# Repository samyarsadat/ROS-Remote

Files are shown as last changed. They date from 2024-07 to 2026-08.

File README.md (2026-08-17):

<h1 align="center">The ROS Remote Project</h1>

<p align="center">
	<br>
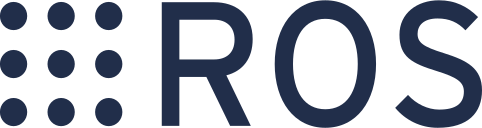
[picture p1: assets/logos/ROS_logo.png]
	<br>
	<br><br>
	
	|
	
	<br><br>
</p>

----
> [!NOTE]
> All features of the remote are currently functional; however, further development is expected.

<br>

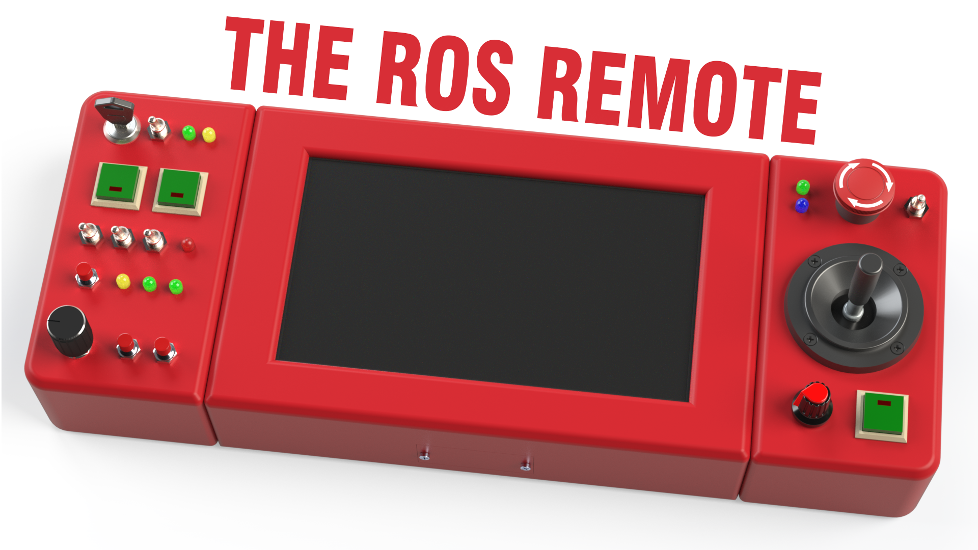
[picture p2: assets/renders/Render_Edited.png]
3D render of ROS Remote CAD drawings

This is a 3D render of the CAD drawings.

<br>

## Overview
The ROS Remote is a comprehensive remote controller for ROS-based robots. The hardware can, of course, be used with any robot, given that specific software has been prepared for the remote.

<br>

### Hardware
The remote houses a 7-inch Waveshare touchscreen, a Raspberry Pi 4B 8GB (you can use a 4GB Pi, or a Pi 5 as well, bu I wouldn't recommend anything below the Pi 4), a Raspberry Pi Pico (Pico 1, though a Pico 2 can also be used with some changes to the build configuration of the firmware), and a USB power bank with enough output current capacity to power the Pi and display (3A should be enough. Must be no larger than 62 x 92 x 24mm, please see CAD drawings).

The buttons, switches, and LEDs are all connected to the Raspberry Pi Pico (except for the rotary encoder and three toggle switches on the left side, which are directly connected to the Pi 4's GPIO pins). The Pico exposes two HID device interfaces. One is a generic joystick interface (for buttons, switches, 2-axis joystick, and potentiometer), and the other is a "custom" (vendor-defined HID reports) interface for controlling the LEDs.

<br>

### Software
The `joy_linux` ROS driver package can be used for publishing data from the joystick interface as a `sensor_msgs/msg/Joy` message to a given topic, and the `joy_teleop` package can be used for robot teleopertation using the `Joy` message. A custom driver package can be found in this repository for interfacing with the LEDs using ROS.

A custom GUI has also been prepared for the screen, which can display a camera feed as well as data from a number of other sensors. This GUI program is designed specifically for use with my [ROS Robot Project](https://github.com/samyarsadat/ROS-Robot), and it is also slightly lacking in terms of performance.

I plan on overhauling this program to improve performance, and make it robot-agnostic. As it stands, any robot which accepts `geometry_msgs/msg/Twist` messages can be teleoperated using the remote with minimal configuration. Additionally, RViz can be used for visualizations, camera feed display, etc. until the remote's own custom GUI program is made robot-agnostic.

You can, of course, write your own programs to change the states of the remote's LEDs, or perform arbitrary actions upon button presses, etc. as they are/can be exposed as standard ROS nodes. The hardware is quite flexible.

<br>

## File Structure
There are 5 folders in this repository.\
Their names and purposes are as follows:

**.github**\
GitHub issue templates, pull request templates, etc.

**assets**\
Assets used on GitHub (such as images used in this README file).

**cad_files**\
3D CAD design files and 3D printing files.

**electronics**\
Circuit diagrams, and other electrical information.

**source_code**\
Source code for the remote touch UI and Raspberry Pi Pico firmware.<br>

<br>

## Contact
You can contact me via e-mail.\
E-mail: samyarsadat@gigawhat.net\

If you think that you have found a bug or issue please report it [here](../../issues).

<br>

## Contributing
Please take a look at [CONTRIBUTING.md](CONTRIBUTING.md) for contributing.

<br>

---
Copyright © 2024-2025 Samyar Sadat Akhavi.

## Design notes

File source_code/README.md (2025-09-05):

## Software Overview
This project uses ROS 2 Jazzy Jalisco and Ubuntu 24.04 LTS.

<br>

### Raspberry Pi Pico (`pico_ws`)
The source code for the firmware of the Raspberry Pi Pico, all build-related configuration files, and configuration files for a devcpntainer can be found in this directory.

<br>

### Remote GUI (`ros_ws_remote`)
The source code for all ROS 2 packages related to the remote's Graphical User Interface and configuration files for a devcontainer can be found in this directory. The `deployment` subdirectory also contains BASH scripts meant to assist with setup and deployment on a Raspberry Pi Single-Board Computer.

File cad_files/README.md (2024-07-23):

## CAD Files:

### .SLDPRT & .SLDASM:
These files are for people that have access to Solidworks.<br>
These files are ideal for editing.<br>

<br>

### .STEP:
These are editable files that can be opened with almost any CAD software.<br>
These are for people that want to edit the project but don't have Solidworks.<br>

<br>

### .STL:
These are non-editable files used for 3D printing.<br>
They can be easily imported into all 3D printer slicer software.<br>

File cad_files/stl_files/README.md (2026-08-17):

### 3D Printing details:
   - I recommend PLA filament, with 0.25mm layer height, and about 25% infill.

<br>

#### Quantities:
    - 1X Housing_Center_Access_Cover.stl
    - 1X Housing_Center_Backplate.stl
    - 1X Housing_Center_LCD_Brace.stl
    - 1X Housing_Center.stl
    - 1X Housing_Left.stl
    - 1X Housing_Right.stl
    - 2X Housing_Sides_Backplate.stl
    - 1X RPi_Fan_Mount.stl (optional)

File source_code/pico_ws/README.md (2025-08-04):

## Pico Firmware Pre-built Binaries
~~If you don't want to build MicroROS and the Pico firmware from source, pre-built `.uf2` binaries can be found in the `build/src` folder.~~<br>
Please take a look at the [`pico-build` workflow](https://github.com/samyarsadat/ROS-Remote/actions/workflows/pico-build.yml) artifact called 
`pico_binary_artifacts` for the latest binary builds.

#### Action Status
<br>


<br>
<br>

**NOTE: This devcontainer and the following instructions are written with the assumption that the host machine running Docker runs Linux (specifically, Ubuntu)!
If you're using Windows (and can't dualboot Linux), please use the Windows Subsystem for Linux (WSL) to run Docker.**<br>

## Note On Devcontainer
When re-building the devcontainer, the re-build might fail the first time.<br>
In this case, simply retry the build a second time.<br>
<br>
You might have to wait (even after the devcontainer has started) for the MicroROS tools to install.<br>
Reload the devcontainer after you have verified that the MicroROS tools have installed successfully.<br>
(Check whether `~/pico_ws/libmicroros/src/micro_ros_setup/install` exists.)<br>
<br>
When prompted to select a build kit by the CMake Tools extension, select `GCC [version] arm-none-eabi`.

<br>

## Note On Using Debug Probes
If you're using a debug probe (such as the Raspberry Pi Debug Probe), make sure to create
a file named `60-openocd.rules` in `/etc/udev/rules.d` on the host machine (not the devcontainer)
and copy the contents of `https://github.com/raspberrypi/openocd/blob/rp2040-v0.12.0/contrib/60-openocd.rules`
into it. This is so that the probe can be accessed witout having to use `sudo`, which is needed when using
the Cortex-Debug extension in VSCode.<br>
<br>
Run `udevadm control --reload` (again, on the host machine) to make sure that the new rules take effect.

<br>

## Updating the FreeRTOS Kernel
Discard all changes to the submodule repository, pull the latest version, and rebuild the devcontainer.

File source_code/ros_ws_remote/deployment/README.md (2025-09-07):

These scripts are for setting up, running, and updating the ROS Remote GUI. The GUI should be run on a Raspberry Pi (4B 8GB in my case, but a model with less RAM will also work) running Ubuntu 24.04 LTS. Raspberry Pi OS will not work.

You should first run the setup script, then you can add the `run_gui.bash` script to start up the list of startup programs using the GNOME "Startup Applications" app. Be sure to specify the `-r` flag for the `run_gui.bash` script. This makes sure that the screen resolution is set properly. You can enter this into the "Command" field:
```
/bin/bash "/home/[YOUR USERNAME]/ros_remote/source_code/ros_ws_remote/deployment/run_gui.bash" -r
```
Replace `[YOUR USERNAME]` with your username.

<br>

## Note on Wayland
These scripts are written with the assumption that the X Window System is being used. If you are using Wayland, you must either modify these scripts yourself, or you must switch to X11.

On Ubuntu, you can switch to X11 by logging out, clicking on the settings icon, selecting "Ubuntu on Xorg", and then entering your passcode and logging in normally. You only need to do this once, as the change is persistent.

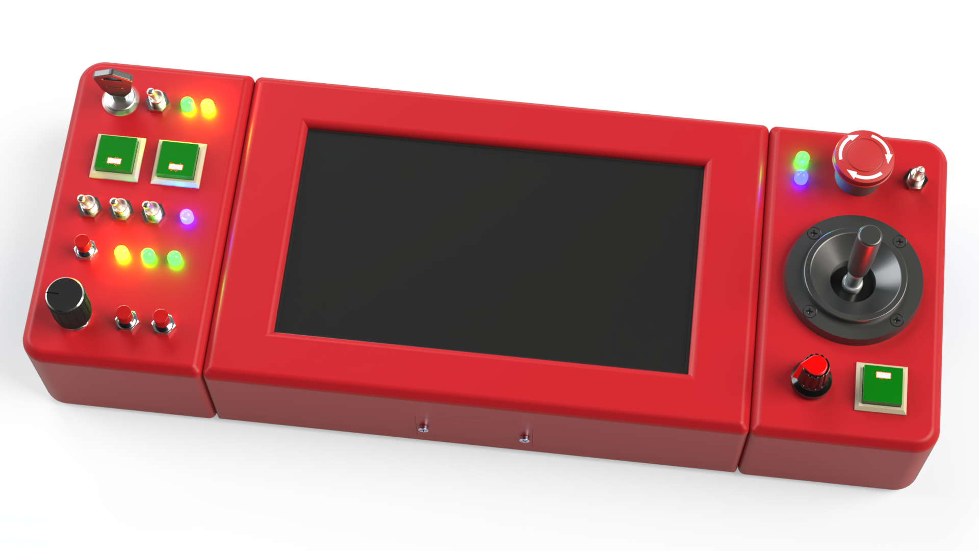
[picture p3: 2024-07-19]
assets/renders/SWVS_Render_Illuminated.png

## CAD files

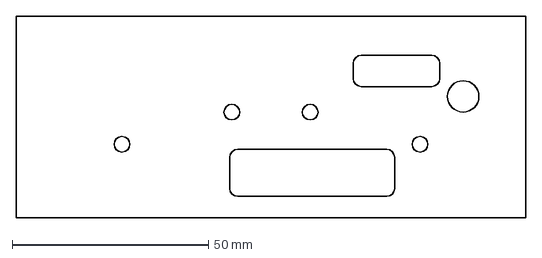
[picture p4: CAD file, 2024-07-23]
cad_files/Housing_Center_Left_Side_Interface.DXF
130.0 x 51.5 mm

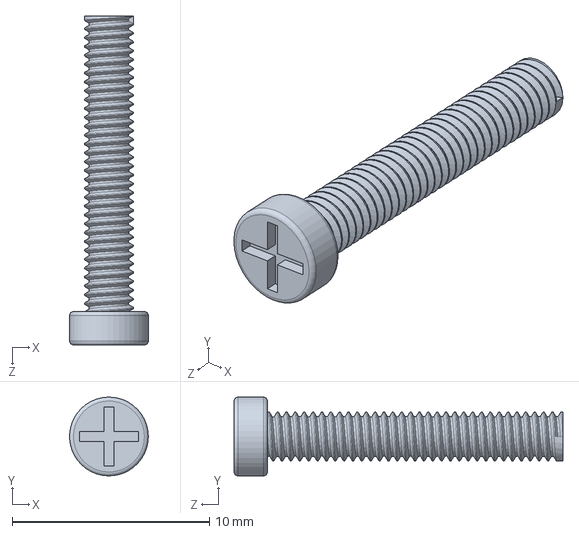
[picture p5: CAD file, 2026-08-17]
cad_files/solidworks_assets/parts/M2.5_15.SLDPRT
3.99 x 4.00 x 16.7 mm

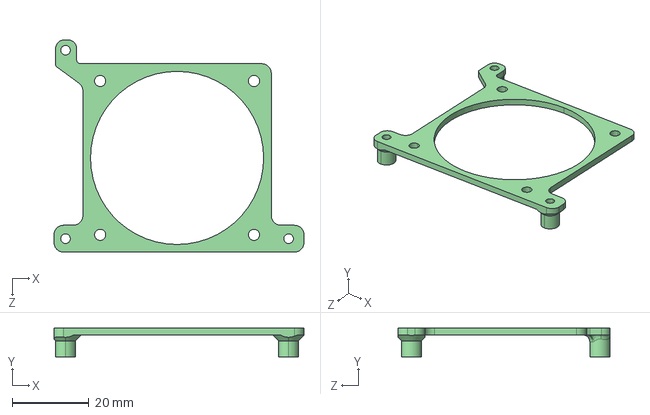
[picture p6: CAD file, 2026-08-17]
cad_files/step_files/RPi_Fan_Mount.STEP
65.0 x 7.50 x 55.2 mm

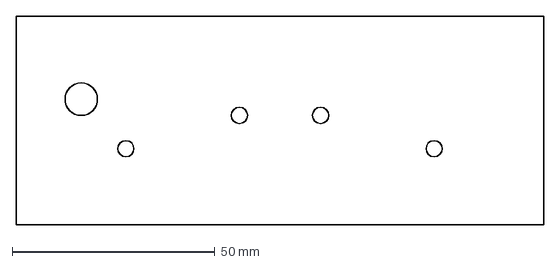
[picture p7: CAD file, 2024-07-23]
cad_files/Housing_Center_Right_Side_Interface.DXF
130.0 x 51.5 mm

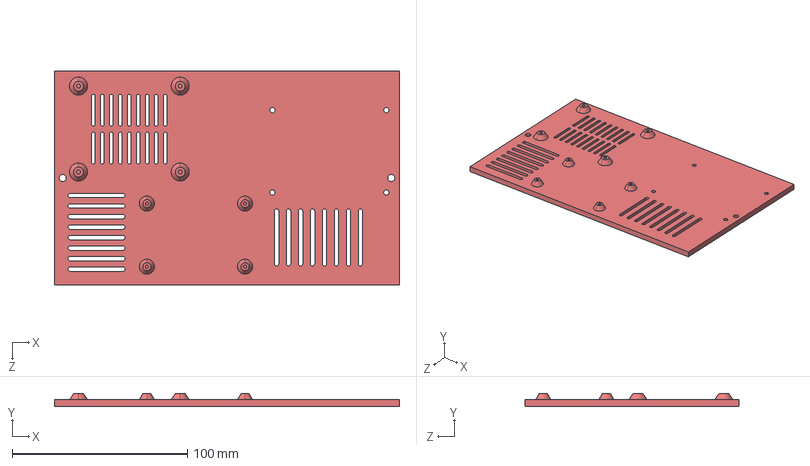
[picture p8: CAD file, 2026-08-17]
cad_files/step_files/Housing_Center_Backplate.STEP
196.8 x 7.50 x 121.8 mm

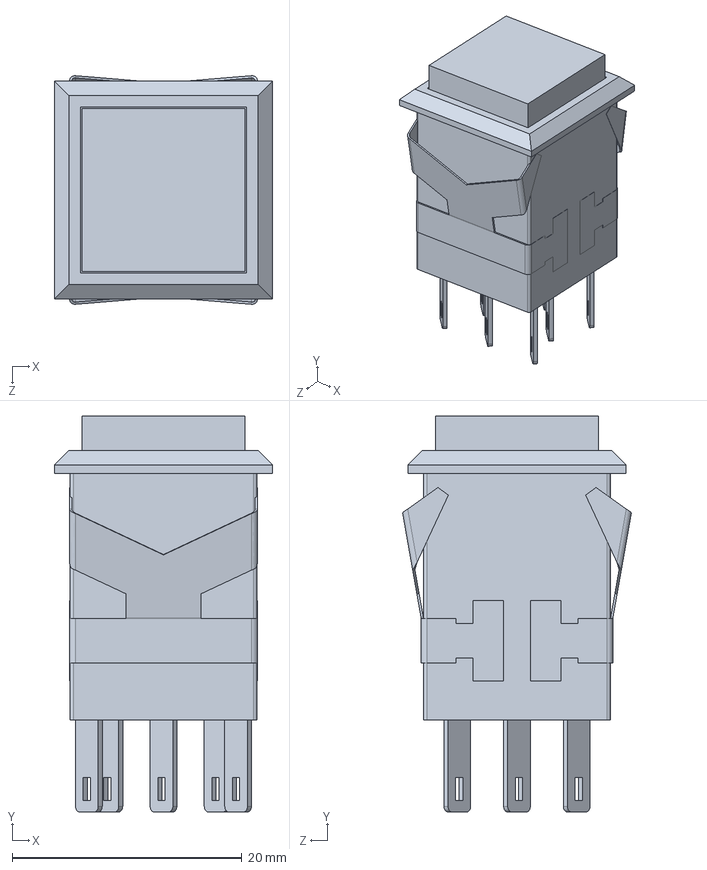
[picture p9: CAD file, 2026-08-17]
cad_files/solidworks_assets/parts/KD2-2X_button_translucent.SLDPRT
19.0 x 34.5 x 19.9 mm

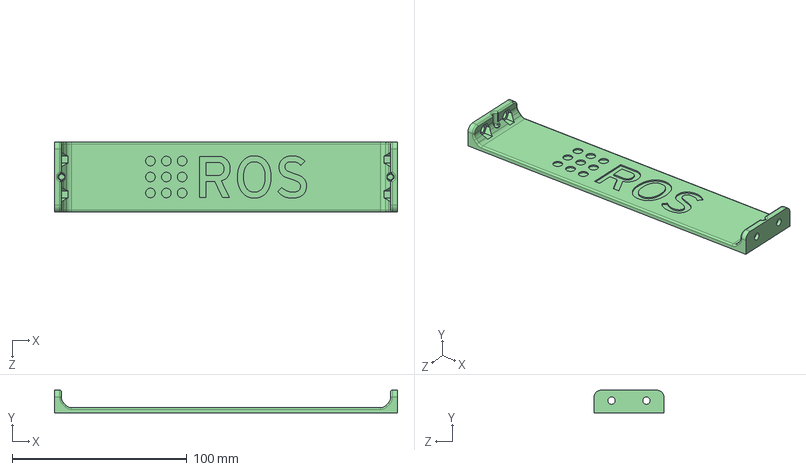
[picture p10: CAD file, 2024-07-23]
cad_files/step_files/Housing_Center_LCD_Brace.STEP
196.5 x 13.0 x 40.0 mm

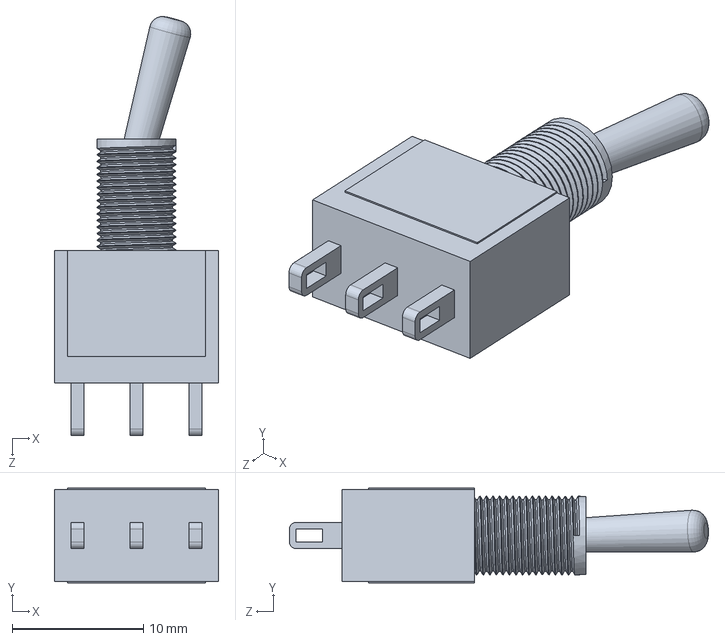
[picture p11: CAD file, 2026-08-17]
cad_files/solidworks_assets/parts/Toggle_Switch.SLDPRT
12.5 x 7.20 x 31.9 mm

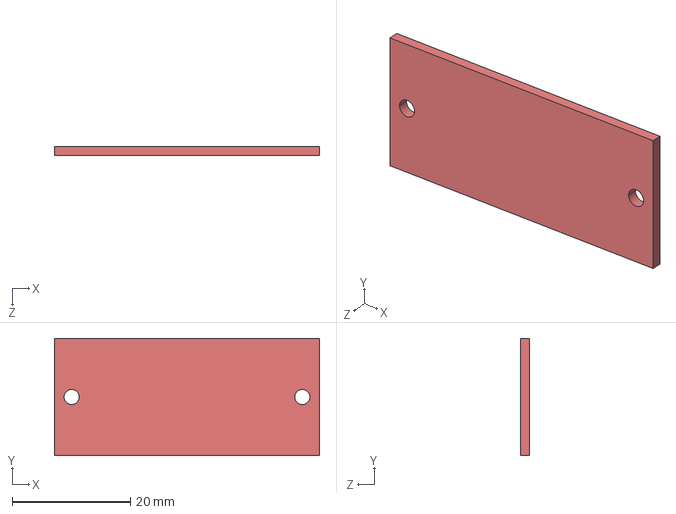
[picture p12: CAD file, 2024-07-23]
cad_files/step_files/Housing_Center_Access_Cover.STEP
44.8 x 19.8 x 1.50 mm

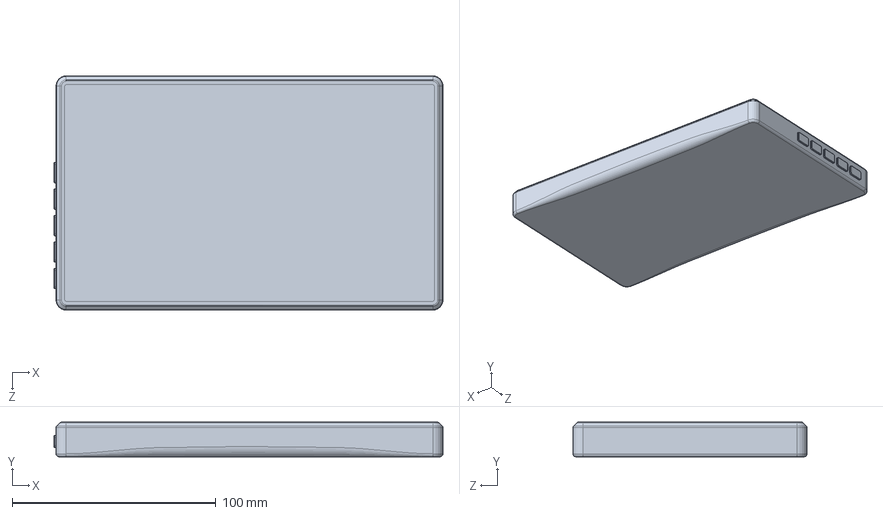
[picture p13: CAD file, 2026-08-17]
cad_files/solidworks_assets/parts/Waveshare_7_inch_HDMI_LCD_H.SLDPRT
191.0 x 17.0 x 115.0 mm

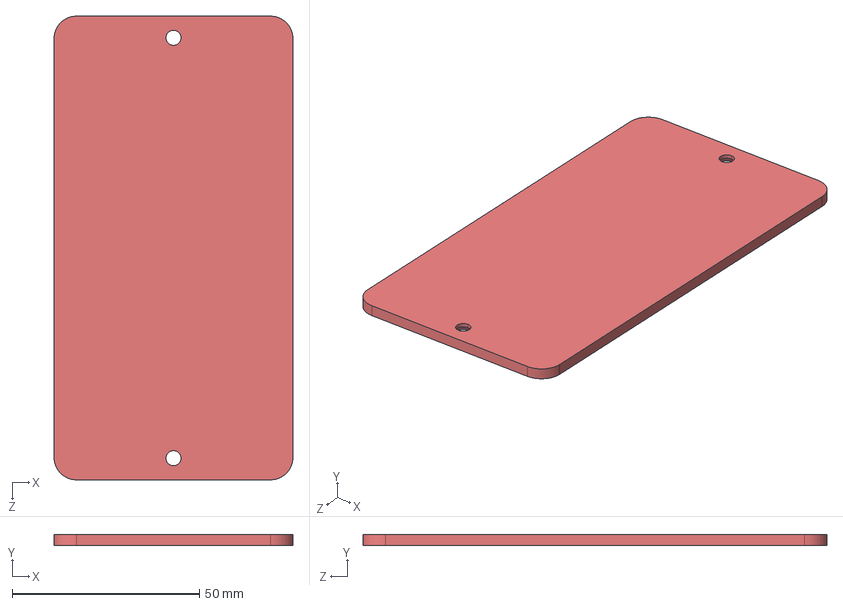
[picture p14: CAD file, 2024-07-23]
cad_files/step_files/Housing_Sides_Backplate.STEP
63.8 x 3.00 x 123.8 mm

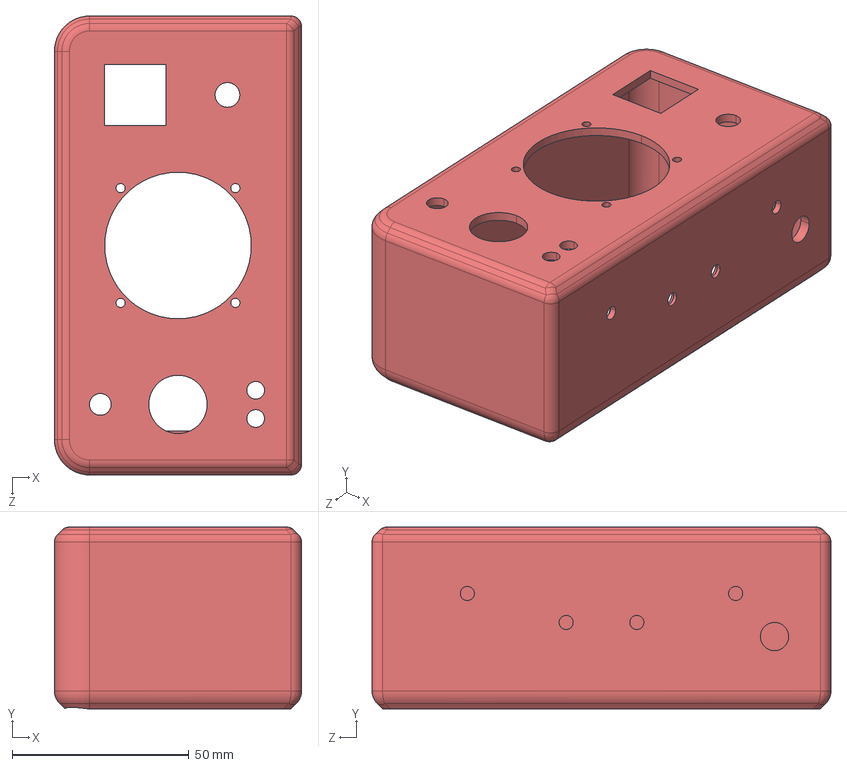
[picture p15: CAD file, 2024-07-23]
cad_files/step_files/Housing_Right.STEP
70.0 x 51.5 x 130.0 mm

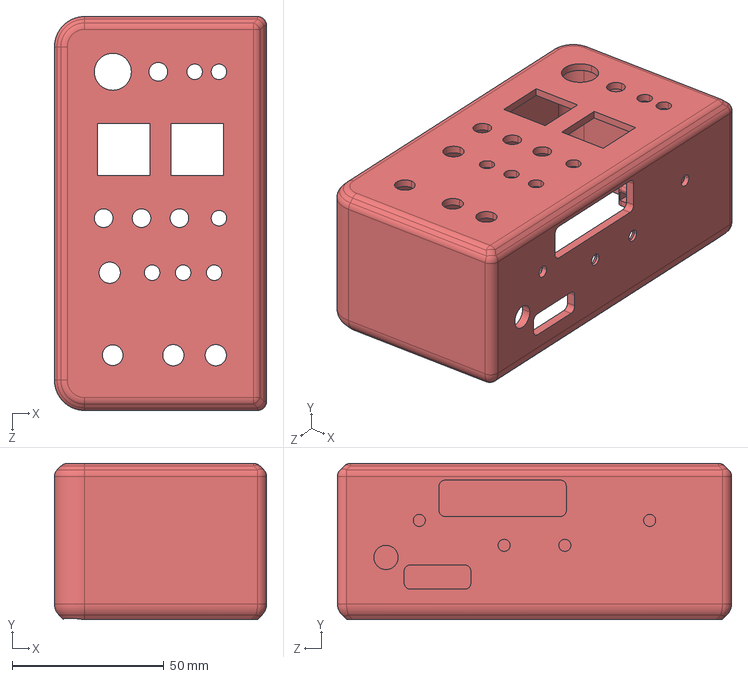
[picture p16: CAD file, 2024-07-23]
cad_files/step_files/Housing_Left.STEP
70.0 x 51.5 x 130.0 mm

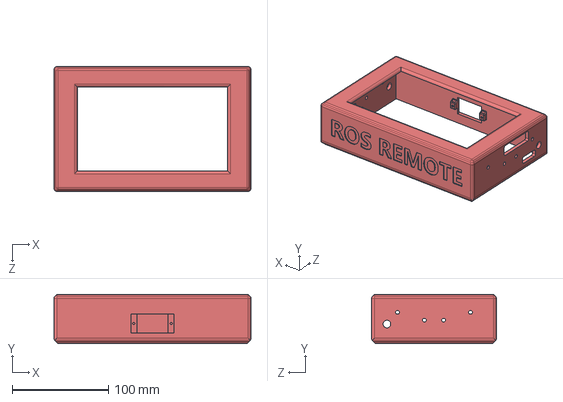
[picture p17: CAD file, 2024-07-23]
cad_files/step_files/Housing_Center.STEP
205.0 x 51.5 x 130.0 mm

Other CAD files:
cad_files/solidworks_assets/parts/Generic_Power_Bank_Representation.SLDPRT
cad_files/solidworks_assets/parts/40x60mm_protoboard.SLDPRT
cad_files/solidworks_assets/parts/Red_led.SLDPRT
cad_files/solidworks_assets/parts/Yellow_led.SLDPRT
cad_files/Housing_Center.SLDPRT
cad_files/Housing_Center_Access_Cover.SLDPRT
cad_files/Housing_Center_Backplate.SLDPRT
cad_files/Housing_Center_LCD_Brace.SLDPRT
cad_files/Housing_Left.SLDPRT
cad_files/Housing_Right.SLDPRT
cad_files/Housing_Sides_Backplate.SLDPRT
cad_files/RPi_Fan_Mount.SLDPRT
cad_files/solidworks_assets/parts/12mm_key_operated_switch.step
cad_files/solidworks_assets/parts/16mm_e-stop_button.SLDPRT
cad_files/solidworks_assets/parts/20_pin_female_header_2.54mm.step
cad_files/solidworks_assets/parts/20_pin_male_header_2.54mm.step
cad_files/solidworks_assets/parts/7mm_Momentary_Button.SLDPRT
cad_files/solidworks_assets/parts/Blue_led.SLDPRT
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

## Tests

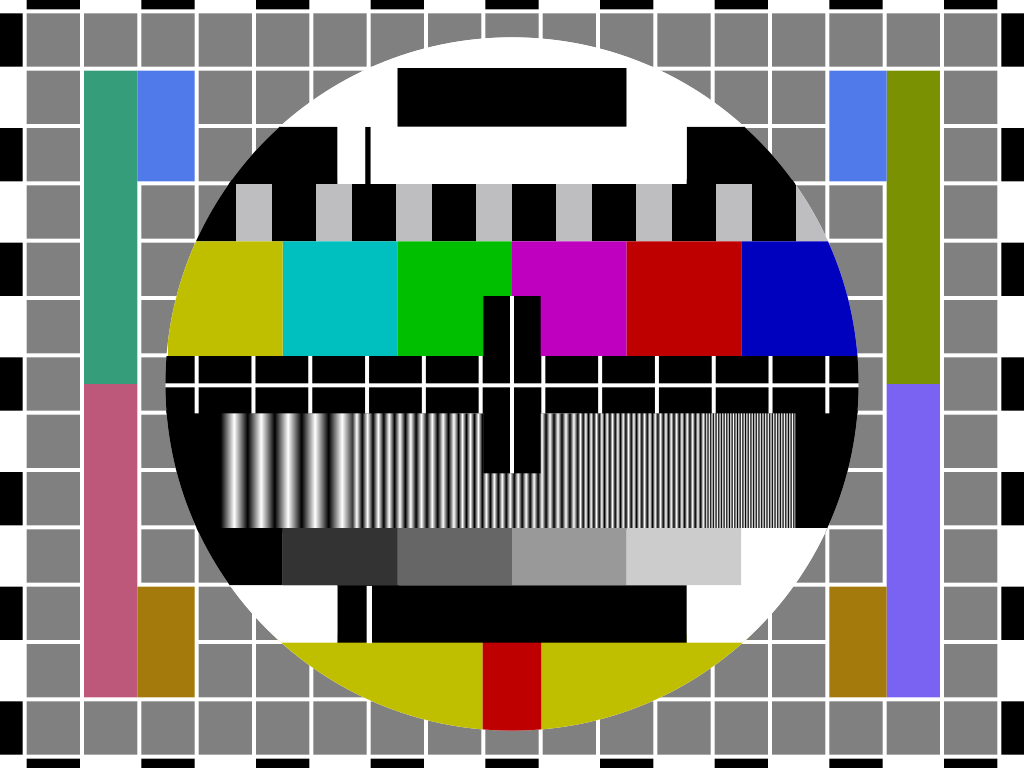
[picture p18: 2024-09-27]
source_code/ros_ws_remote/src/test_camera_publisher/test_camera_publisher/test_images/pm5544.png

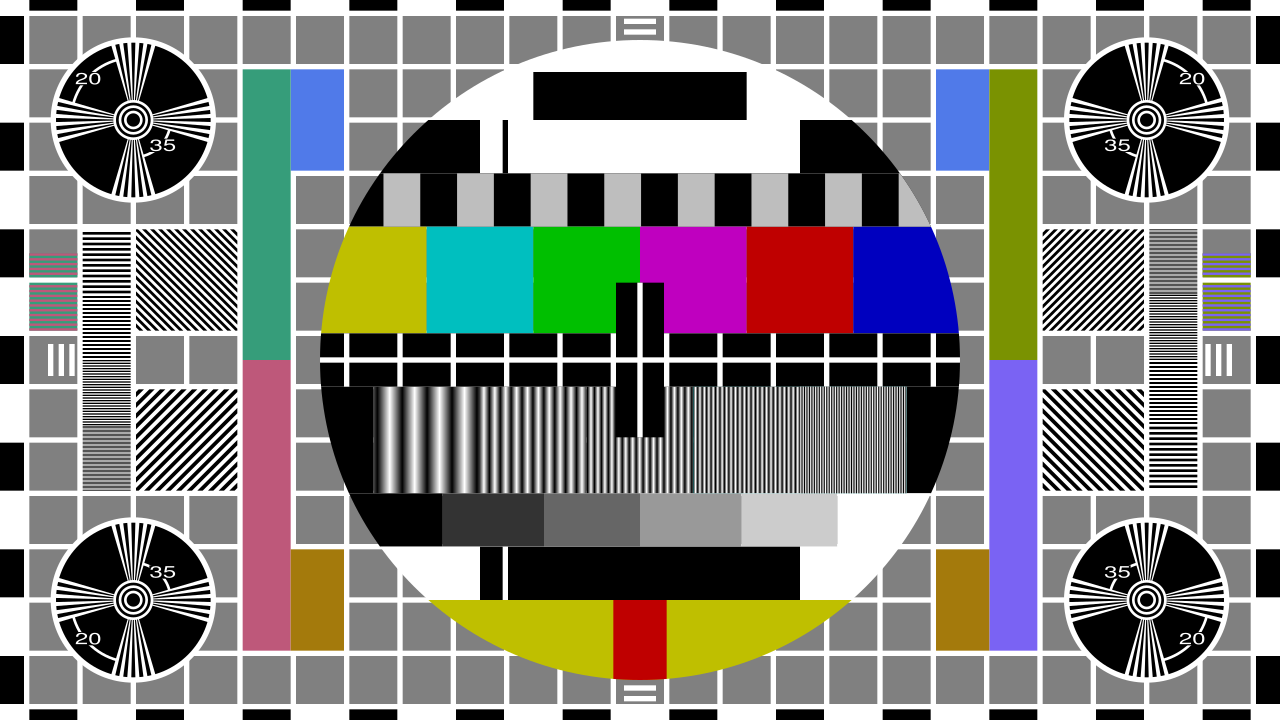
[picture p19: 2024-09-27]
source_code/ros_ws_remote/src/test_camera_publisher/test_camera_publisher/test_images/pm5644.png

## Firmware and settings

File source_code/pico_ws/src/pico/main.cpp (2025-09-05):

/*
    The ROS remote project - Raspberry Pi Pico firmware
    Copyright 2024-2025 Samyar Sadat Akhavi.
    Written by Samyar Sadat Akhavi, 2024-2025.
 
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
    You should have received a copy of the GNU General Public License
    along with this program.  If not, see <https://www.gnu.org/licenses/>.
*/

#include "pico/stdlib.h"
#include "hardware/adc.h"
#include "FreeRTOS.h"
#include "timers.h"
#include "utils_lib/hardware.h"
#include "io/leds.h"
#include "io/buttons.h"
#include "utils_lib/adc/adc_lock.h"
#include "diagnostics.h"
#include "common/opassert.h"
#include "tusb/hid_report_senders.h"
#include "config/sw_defs.h"
#include "bsp/board_api.h"
#include "tusb.h"
#include "state_management.h"
#include "pico/unique_id.h"
#include "utils_lib/perf/exec_interval.h"
#include "config/version.h"


// ---- Global variables ----
char pico_unique_id[PICO_UNIQUE_BOARD_ID_SIZE_BYTES * 2 + 1];
alarm_pool_t *core_1_alarm_pool = nullptr;
TimerHandle_t status_led_timer = nullptr, idle_hid_report_timer = nullptr;
TaskHandle_t tusb_spin_task_th = nullptr;
bool mount_init = false, resume_init = false;


// ---- FreeRTOS task stack overflow hook ----
void vApplicationStackOverflowHook(TaskHandle_t xTask, char* pcTaskName) {
    (void) xTask;
    panic("FreeRTOS stack overflow in task: %s", pcTaskName);
}

// ---- FreeRTOS malloc failure hook ----
void vApplicationMallocFailedHook() {
    panic("FreeRTOS malloc failed!");
}


// ---- LED flash state handler ----
void status_led_timer_call(TimerHandle_t timer) {
    TickType_t timer_period;
    bool led_always_on = false;

    if (mount_init && resume_init) {
        led_always_on = true;
        timer_period = pdMS_TO_TICKS(STAT_LED_IDLE_CHECK_MS);
    } else if (mount_init && !resume_init) {
        led_always_on = false;
        timer_period = pdMS_TO_TICKS(STAT_LED_SUSPENDED_MS);
    } else {
        led_always_on = false;
        timer_period = pdMS_TO_TICKS(STAT_LED_UNMOUNTED_MS);
    }

    if (xTimerGetPeriod(timer) != pdMS_TO_TICKS(timer_period)) {
        (void) xTimerChangePeriod(timer, pdMS_TO_TICKS(timer_period), TIMER_COMMAND_TIMEOUT_T);
    }

    gpio_put(PICO_DEFAULT_LED_PIN, !gpio_get(PICO_DEFAULT_LED_PIN) || led_always_on);
}

// ---- Idle HID report timer ----
#define _IDLE_HID_NOTIFY_CHECK(name)                                                  \
    if (curr_time - name##_lst > curr_tmr_period - IDLE_NOTIFY_TIME_CHECK_MARGIN_T) { \
        (void) xTaskNotify(name##_th, 1, eSetValueWithOverwrite);                     \
    }

void idle_hid_report_timer_call(TimerHandle_t timer) {
    (void) timer;

    // In case the timer stop command fails for whatever reason.
    if (resume_init && mount_init) {
        assert(report_axes_states_th != NULL && report_button_states_th != NULL && 
               report_sw_states_th != NULL && report_pot_state_th != NULL);
        
        TickType_t curr_tmr_period = xTimerGetPeriod(timer);
        TickType_t curr_time = xTaskGetTickCount();
        
        // Note: This is only for the joystick HID interface.
        _IDLE_HID_NOTIFY_CHECK(report_axes_states)
        _IDLE_HID_NOTIFY_CHECK(report_sw_states)
        _IDLE_HID_NOTIFY_CHECK(report_pot_state)
        _IDLE_HID_NOTIFY_CHECK(report_button_states)
    }
}

// ---- TinyUSB spin task ----
void tusb_spin_task(void *parameters) {
    (void) parameters;
    LOG(LOG_LVL_INFO, "TinyUSB task started!");
    TickType_t wake = xTaskGetTickCount();
    uint32_t last_exec_time = 0;

    while (true) {
        CHECK_EXEC_INTERVAL_DBG(&last_exec_time, (TUSB_TASK_EXEC_RATE_MS + 2), "USB task execution time limit exceeded!");

        if (tud_task_event_ready()) {
            tud_task();
        }

        xTaskDelayUntil(&wake, pdMS_TO_TICKS(TUSB_TASK_EXEC_RATE_MS));
    }
}


// ---- Setup function (core 0) ----
void setup(void *parameters) {
    (void) parameters;
    LOG(LOG_LVL_INFO, "Core 0 setup task started!");
    LOG(LOG_LVL_INFO, "Hardware initialization.");
    
    // Force SMPS into PWM mode
    init_pin(PICO_SMPS_MODE_PIN, OUTPUT);
    gpio_put(PICO_SMPS_MODE_PIN, true);

    // Pin init
    init_pin(PICO_DEFAULT_LED_PIN, OUTPUT);
    init_pin(RIGHT_TOP_TOGGLE_SW_PIN, INPUT_PULLUP);
    init_pin(LEFT_KEY_SW_PIN, INPUT_PULLUP);
    init_pin(LEFT_TOP_TOGGLE_SW_PIN, INPUT_PULLUP);
    init_pin(RIGHT_E_STOP_BTN_PIN, INPUT_PULLUP);
    init_pin(RIGHT_KD2_BTN_PIN, INPUT_PULLUP);
    init_pin(JOYSTICK_Y_AXIS_PIN, INPUT_ADC);
    init_pin(JOYSTICK_X_AXIS_PIN, INPUT_ADC);
    init_pin(POTENTIOMETER_PIN, INPUT_ADC);
    init_momentary_button_pins();
    init_led_pins();

    // ADC init
    adc_init();
    opassert(adc_init_mutex());

    // Perform LED test
    LOG(LOG_LVL_INFO, "Performing LED test.");
    leds_test_blocking();

    // Create FreeRTOS timers
    LOG(LOG_LVL_INFO, "Creating FreeRTOS software timers.");
    status_led_timer = xTimerCreate("usb_status_led", pdMS_TO_TICKS(STAT_LED_UNMOUNTED_MS), pdTRUE, nullptr, status_led_timer_call);
    idle_hid_report_timer = xTimerCreate("idle_hid_report", pdMS_TO_TICKS(DEFAULT_IDLE_REPORT_INTERVAL_MS), pdTRUE, nullptr, idle_hid_report_timer_call);
    assert(status_led_timer != nullptr && idle_hid_report_timer != nullptr);
    led_timers_init();

    // Start the status LED blink timer
    (void) xTimerStart(status_led_timer, TIMER_COMMAND_TIMEOUT_T);

    // TinyUSB initialization
    LOG(LOG_LVL_INFO, "TinyUSB initialization.");
    tusb_init();
    (void) xTaskCreate(tusb_spin_task, "tusb_task", TUSB_TASK_STACK_DEPTH, nullptr, TUSB_TASK_PRIORITY, &tusb_spin_task_th);
    vTaskCoreAffinitySet(tusb_spin_task_th, 1 << 0);

    // Delete setup task
    vTaskDelete(nullptr);
}

// ---- Setup function (core 1) ----
void setup1(void *parameters) {
    (void) parameters;
    LOG(LOG_LVL_INFO, "Core 1 setup task started!");

    // Create alarm pool for core 1 timers
    LOG(LOG_LVL_INFO, "Creating core 1 alarm pool.");
    core_1_alarm_pool = alarm_pool_create(2, 3);

    // Delete setup task
    vTaskDelete(nullptr);
}


// ---- Device state management ----
void enter_state_resumed() {
    if(!resume_init && mount_init) {
        LOG(LOG_LVL_INFO, "Entering resumed state.");

        start_hid_reporters(core_1_alarm_pool);
        led_timers_start();
        leds_enable_override(false);
        set_led_outputs();
        vTaskResume(button_poll_task_th);
        opequal(xTimerStart(idle_hid_report_timer, TIMER_COMMAND_TIMEOUT_T), pdPASS);

        resume_init = true;
    }
}

void enter_state_suspended() {
    if (resume_init && mount_init) {
        LOG(LOG_LVL_INFO, "Entering suspended state.");

        stop_hid_reporters();
        led_timers_stop();
        leds_enable_override(true);
        vTaskSuspend(button_poll_task_th);
        opequal(xTimerStop(idle_hid_report_timer, TIMER_COMMAND_TIMEOUT_T), pdPASS);

        for (uint i = 0; i < NUMBER_OF_LEDS; i++) {
            gpio_put_pwm(led_pins_order[i], 0);
        }

        resume_init = false;
    }
}

void enter_state_mounted() {
    if (!mount_init) {
        LOG(LOG_LVL_INFO, "Entering mounted state, creating reporter tasks.");
        
        create_hid_reporter_tasks();
        create_button_poll_task();
        opequal(xTimerChangePeriod(idle_hid_report_timer, pdMS_TO_TICKS(DEFAULT_IDLE_REPORT_INTERVAL_MS), TIMER_COMMAND_TIMEOUT_T), pdPASS);
        mount_init = true;

        enter_state_resumed();
    }
}

void enter_state_unmounted() {
    if (mount_init) {
        LOG(LOG_LVL_INFO, "Entering unmounted state.");
        
        enter_state_suspended();
        delete_hid_reporter_tasks();
        delete_button_poll_task();

        for (uint i = 0; i < NUMBER_OF_LEDS; i++) {
            set_led_state(i, LED_SOLID_PWM, 0);
        }

        mount_init = false;
    }
}


// ****** END OF MAIN PROGRAM *******
// *********** ENTRYPOINT ***********
int main() {
    // Load the unique ID
    pico_get_unique_board_id_string(pico_unique_id, sizeof(pico_unique_id));

    // Logging over UART, USB HID used for data.
    stdio_uart_init();
    board_init();
    LOG(LOG_LVL_INFO, "Board init, program starting.");
    LOG(LOG_LVL_INFO, "Firmware build: %s", FIRMWARE_VERSION_FULL_STRING);

    if (!logger.init_mutex()) {
        LOG(LOG_LVL_ERROR, "Logger mutex initialization failed!");
        return 0;
    }

    // Setup function tasks
    LOG(LOG_LVL_INFO, "Creating setup tasks.");
    xTaskCreateAffinitySet(setup, "setup_core0", SETUP_TASK_STACK_DEPTH, nullptr, SETUP_TASK_PRIORITY, (1 << 0), nullptr);
    xTaskCreateAffinitySet(setup1, "setup_core1", SETUP_TASK_STACK_DEPTH, nullptr, SETUP_TASK_PRIORITY, (1 << 1), nullptr);

    // Start FreeRTOS scheduler
    LOG(LOG_LVL_INFO, "Starting FreeRTOS scheduler...");
    vTaskStartScheduler();

    // We should never get to this point!
    LOG(LOG_LVL_FATAL, "Program exit. Scheduler start failed!");
    return 0;
}

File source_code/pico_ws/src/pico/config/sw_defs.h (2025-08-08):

/*
    The ROS remote project - Firmware software definitions
    Copyright 2025 Samyar Sadat Akhavi.
    Written by Samyar Sadat Akhavi, 2025.
 
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
    You should have received a copy of the GNU General Public License
    along with this program.  If not, see <https://www.gnu.org/licenses/>.
*/

#pragma once
#include "pico_log_lib/internal/common.h"


// Logger config
#define LOGGER_LOG_LEVEL   LOG_LVL_DEBUG
#define LOGGER_LOG_FORMAT  "[%TSTMP%] [%LVL%] [%FUNC%:%LINE%] [%TASK%]: %MSG%"

// Repeating timer intervals
#define SW_STATE_REPORT_INTERVAL    50    // In milliseconds
#define AXES_STATE_REPORT_INTERVAL  50    // In milliseconds
#define POT_STATE_REPORT_INTERVAL   50    // In milliseconds
#define LED_SLOW_FLASH_INTERVAL     800   // In milliseconds
#define LED_FAST_FLASH_INTERVAL     400   // In milliseconds
#define LED_FADE_EXEC_INTERVAL      10    // In milliseconds

// LEDs
#define LED_FAST_FADING_TIME_MS             400   // In milliseconds
#define LED_SLOW_FADING_TIME_MS             800   // In milliseconds
#define LED_TEST_DELAY_TICKS                100   // In FreeRTOS ticks
#define LED_STATE_REPORT_RETRY_COOLDOWN_MS  10    // In milliseconds

// Joystick
#define JOYSTICK_X_DEADZONE                100
#define JOYSTICK_Y_DEADZONE                100
#define JOYSTICK_X_CENTER_OFFSET           0
#define JOYSTICK_Y_CENTER_OFFSET           0
#define JOYSTICK_Y_INVERTED                false
#define JOYSTICK_X_INVERTED                false
#define JOYSTICK_AXIS_SWAP_BUTTON_ENABLED  true
#define JOYSTICK_AXIS_SWAP_BUTTON_NUM      1

// Potentiometer
#define POTENTIOMETER_INVERTED  true

// Momentary buttons
#define BUTTON_BOUNCE_TIME_MS    50   // De-bouncing bounce time, in milliseconds
#define BUTTON_POLL_INTERVAL_MS  10   // Polling task exec. interval, in milliseconds

// FreeRTOS task stack sizes (all in FreeRTOS words)
#define SETUP_TASK_STACK_DEPTH  1024
#define TIMER_TASK_STACK_DEPTH  512
#define TUSB_TASK_STACK_DEPTH   2048

// Status LED
#define STAT_LED_IDLE_CHECK_MS     1000   // In milliseconds
#define STAT_LED_SUSPENDED_MS      500    // In milliseconds
#define STAT_LED_UNMOUNTED_MS      250    // In milliseconds

// Task priorities
#define SETUP_TASK_PRIORITY               (configMAX_PRIORITIES - 1)
#define TUSB_TASK_PRIORITY                (configMAX_PRIORITIES - 1)
#define AXES_REPORT_TASK_PRIORITY         (configMAX_PRIORITIES - 2)
#define BUTTON_REPORT_TASK_PRIORITY       (configMAX_PRIORITIES - 2)
#define BUTTON_POLL_TASK_PRIORITY         (configMAX_PRIORITIES - 2)
#define SW_REPORT_TASK_PRIORITY           (configMAX_PRIORITIES - 3)
#define POT_REPORT_TASK_PRIORITY          (configMAX_PRIORITIES - 3)
#define LED_STATES_REPORT_TASK_PRIORITY   (configMAX_PRIORITIES - 4)

// Idle HID report
#define DEFAULT_IDLE_REPORT_INTERVAL_MS  1000   // In milliseconds
#define MIN_IDLE_REPORT_INTERVAL_MS      250    // In milliseconds
#define HID_REPORT_IDLE_RATE_UNIT_MS     4      // In milliseconds
#define IDLE_NOTIFY_TIME_CHECK_MARGIN_T  100    // In FreeRTOS ticks

// Misc.
#define TIMER_COMMAND_TIMEOUT_T          500   // In FreeRTOS ticks
#define TUSB_TASK_EXEC_RATE_MS           10    // In milliseconds

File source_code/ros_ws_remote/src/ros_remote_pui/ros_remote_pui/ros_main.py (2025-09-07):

#  The ROS remote project (PUI package)
#  ROS setup, node, and executor
#  Copyright 2024 Samyar Sadat Akhavi
#  Written by Samyar Sadat Akhavi, 2024.
#
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
import threading
from typing import Union
from rclpy.client import SrvTypeRequest, Client, SrvTypeResponse
from rclpy.node import Node
from rclpy.context import Context
from ros_remote_hid.srv import SetLedState, GetLedStates
from ros_remote_pui.config import RosConfig, RosNames
from sensor_msgs.msg import Joy


# ---- ROS Node ----
class RosNode(Node):
    # Client.call() implementation with timeout.
    def srv_call_with_timeout(self, client: Client, request: SrvTypeRequest, timeout_s: int) -> Union[SrvTypeResponse, None]:
        event = threading.Event()

        def unblock(ftr):
            event.set()

        future = client.call_async(request)
        future.add_done_callback(unblock)

        if not future.done():
            if not event.wait(float(timeout_s)):
                self.get_logger().error(f"Service call failure [{client.srv_name}]: timed out! Cancelling.")
                future.cancel()
                return None

        if future.exception() is not None:
            raise future.exception()
        return future.result()

    def __init__(self, context: Context):
        super().__init__(node_name=RosConfig.NODE_NAME, namespace=RosConfig.NODE_NAMESPACE, context=context)
        self.get_logger().info("Creating subscribers, and services clients...")
        self._joystick_pub = self.create_subscription(Joy, RosNames.JOYSTICK_TOPIC, self._joystick_msg_call, qos_profile=RosConfig.QOS_BEST_EFFORT)
        self.get_led_states_srvcl = self.create_client(GetLedStates, RosNames.GET_LED_STATES_SRV, qos_profile=RosConfig.QOS_RELIABLE)
        self.set_led_state_srvcl = self.create_client(SetLedState, RosNames.SET_LED_STATES_SRV, qos_profile=RosConfig.QOS_RELIABLE)

    def _joystick_msg_call(self, msg: Joy) -> None:
        from ros_remote_pui.remote_state import get_remote_state
        remote_state = get_remote_state()

        if msg.buttons[0] == 1 and not remote_state.left_green_right_btn_en:
            remote_state.left_green_right_btn_en = True
            remote_state._ros_signals.left_r_green_btn_press_sig.emit()
        else:
            remote_state.left_green_right_btn_en = msg.buttons[0] == 1

        # Skip button[1]. It's used as the axis swap button in firmware.

        if msg.buttons[2] == 1 and not remote_state.left_green_kd2_btn_en:
            remote_state.left_green_kd2_btn_en = True
            remote_state._ros_signals.left_l_kd2_btn_press_sig.emit()
        else:
            remote_state.left_green_kd2_btn_en = msg.buttons[2] == 1

        if msg.buttons[3] == 1 and not remote_state.left_red_kd2_btn_en:
            remote_state.left_red_kd2_btn_en = True
            remote_state._ros_signals.left_r_kd2_btn_press_sig.emit()
        else:
            remote_state.left_red_kd2_btn_en = msg.buttons[3] == 1

        if msg.buttons[4] == 1 and not remote_state.left_green_left_btn_en:
            remote_state.left_green_left_btn_en = True
            remote_state._ros_signals.left_l_green_btn_press_sig.emit()
        else:
            remote_state.left_green_left_btn_en = msg.buttons[4] == 1

        remote_state.key_sw_en = msg.buttons[5] == 1
        remote_state.left_top_sw_en = msg.buttons[6] == 1
        remote_state.e_stop_sw_en = msg.buttons[7] == 1
        remote_state.right_kd2_en = msg.buttons[8] == 1
        remote_state.right_sw_en = msg.buttons[9] == 1
        remote_state.potentiometer_val = int(msg.axes[3] * 100)


# ---- Node object ----
_pui_ros_node: RosNode | None = None


# ---- Executor ----
def is_ros_node_initialized() -> bool:
    return _pui_ros_node is not None

def get_ros_node() -> RosNode | None:
    return _pui_ros_node

def init_ros_node(context: Context) -> RosNode:
    global _pui_ros_node
    if not is_ros_node_initialized():
        _pui_ros_node = RosNode(context=context)
        _pui_ros_node.get_logger().info("Node initialized!")
    return _pui_ros_node

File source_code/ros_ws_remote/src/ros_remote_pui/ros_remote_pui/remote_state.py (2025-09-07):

#  The ROS remote project (PUI package)
#  Remote PUI handler. Stores and manages button/sw states and callbacks.
#  Also handles setting LED states.
#  Copyright 2024 Samyar Sadat Akhavi
#  Written by Samyar Sadat Akhavi, 2024.
#
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
import ros_remote_pui.ros_main
import subprocess
import re
from asyncio import Future
from PySide6.QtCore import QTimer, QObject, Signal, Slot, QProcess
from ros_remote_hid.srv import SetLedState, GetLedStates
from ros_remote_gui.main_window import get_main_window
from ros_remote_gui.ros_main import get_ros_node as get_gui_ros_node
from ros_remote_pui.config import ProgramConfig, RpiIoConfig
from datetime import datetime
from std_msgs.msg import Empty, Bool
from std_srvs.srv import SetBool


# ROS signals
class RosSignals(QObject):
    left_l_kd2_btn_press_sig = Signal()
    left_r_kd2_btn_press_sig = Signal()
    left_l_green_btn_press_sig = Signal()
    left_r_green_btn_press_sig = Signal()


# Remote state
class RemoteState:
    key_sw_en: bool
    left_top_sw_en: bool
    left_mid_a_sw_en: bool
    left_mid_b_sw_en: bool
    left_mid_c_sw_en: bool
    e_stop_sw_en: bool
    right_sw_en: bool
    right_kd2_en: bool
    potentiometer_val: int
    joystick_vals: list[int]
    last_joystick_pub: datetime
    max_linear_velocity_mps: float
    max_angular_velocity_rps: float
    left_green_kd2_btn_en: bool
    left_red_kd2_btn_en: bool
    left_green_left_btn_en: bool
    left_green_right_btn_en: bool

    def __init__(self):
        self._ros_signals = RosSignals()
        self._ros_signals.left_l_kd2_btn_press_sig.connect(self.left_l_kd2_btn_press)
        self._ros_signals.left_r_kd2_btn_press_sig.connect(self.left_r_kd2_btn_press)
        self._ros_signals.left_l_green_btn_press_sig.connect(self.left_l_green_btn_press)
        self._ros_signals.left_r_green_btn_press_sig.connect(self.left_r_green_btn_press)

        self.key_sw_en = False          # Lock/unlock remote
        self.left_top_sw_en = False     # Not assigned
        self.left_mid_a_sw_en = False   # Enable/disable camera LEDs (all full-on/full-off)
        self.left_mid_b_sw_en = False   # Not assigned
        self.left_mid_c_sw_en = False   # Not assigned
        self.e_stop_sw_en = False       # Motor controller enable
        self.right_sw_en = False        # Joystick input override/avg with nav select
        self.right_kd2_en = False       # Joystick enable

        self.left_green_kd2_btn_en = False    # Not assigned
        self.left_red_kd2_btn_en = False      # Not assigned
        self.left_green_left_btn_en = False   # UI - previous page
        self.left_green_right_btn_en = False  # UI - next page

        # Get the ID of the touchscreen from Xinput.
        # This will be used when locking/unlocking the remote.
        self._touchscreen_id = None
        xinput_resp = subprocess.run(["xinput", "list"], stdout=subprocess.PIPE, text=True)
        id_matches = re.search(r"touchscreen.*id=(\d+)", xinput_resp.stdout, re.IGNORECASE)
        if id_matches: self._touchscreen_id = id_matches.group(1)

        # Will be True when there is an active call to the motor controller enable service in-progress.
        self._call_to_mtr_ctrl_en_in_progress = False

        # LED-related state
        self._power_led_set = False
        self._mtr_ctrl_last_state = 0   # 0: one or more not enabled, 1: all enabled, 2: data stale
        self._last_battery_led_state = False

        self._sw_state_act_tmr = QTimer()
        self._sw_state_act_tmr.timeout.connect(self._sw_state_act_tmr_call)
        self._sw_state_act_tmr.start(ProgramConfig.SW_ACT_TIMER_INTERVAL_MS)

        from ros_remote_gui.main import qt_app
        qt_app.aboutToQuit.connect(self._set_all_leds_off)

    def _sw_state_act_tmr_call(self) -> None:
        if ros_remote_pui.ros_main.is_ros_node_initialized():
            # Lock/unlock remote
            if self.key_sw_en and get_main_window().isEnabled():
                get_main_window().setEnabled(False)
                if self._touchscreen_id: QProcess.startDetached("/bin/xinput", ["disable", self._touchscreen_id])
                self._make_set_led_request(3, 3, 65535)
            elif (not self.key_sw_en) and (not get_main_window().isEnabled()):
                get_main_window().setEnabled(True)
                if self._touchscreen_id: QProcess.startDetached("/bin/xinput", ["enable", self._touchscreen_id])
                self._make_set_led_request(3, 0, 0)

            # LED states
            if not self._power_led_set:
                self._power_led_set = self._make_set_led_request(4, 0, 32000)

            if get_main_window().power_tab_ui_handler.batt_voltage < ProgramConfig.BATT_WARN_LED_TRIG_VOLT and not self._last_battery_led_state:
                self._last_battery_led_state = self._make_set_led_request(6, 2, 65535)
            elif get_main_window().power_tab_ui_handler.batt_voltage > ProgramConfig.BATT_WARN_LED_TRIG_VOLT and self._last_battery_led_state:
                self._last_battery_led_state = not self._make_set_led_request(6, 0, 0)

            # Motor controller LED
            current_mtr_ctrl_state = 1

            if get_main_window().motor_tab_ui_handler.right_data_stale or get_main_window().motor_tab_ui_handler.left_data_stale:
                current_mtr_ctrl_state = 3
            else:
                if get_main_window().motor_tab_ui_handler.left_ctrl_enabled and get_main_window().motor_tab_ui_handler.right_ctrl_enabled:
                    current_mtr_ctrl_state = 2
                elif (not get_main_window().motor_tab_ui_handler.left_ctrl_enabled) and (not get_main_window().motor_tab_ui_handler.right_ctrl_enabled):
                    current_mtr_ctrl_state = 0

            if current_mtr_ctrl_state != self._mtr_ctrl_last_state:
                success = False

                match current_mtr_ctrl_state:
                    case 0:
                        success = self._make_set_led_request(1, 0, 0)
                    case 1:
                        success = self._make_set_led_request(1, 1, 32000)
                    case 2:
                        success = self._make_set_led_request(1, 0, 32000)
                    case 3:
                        success = self._make_set_led_request(1, 2, 32000)

                if success:
                    self._mtr_ctrl_last_state = current_mtr_ctrl_state
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

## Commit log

2024-07-19 Initial commit.
    [12mm_key_operated_switch.step, 16mm_e-stop_button.SLDPRT, 20_pin_female_header_2.54mm.step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]
2024-07-23 Added submodules for Pico firmware.
2024-07-23 Started work on firmware development.
    [12mm_key_operated_switch.step, 20_pin_female_header_2.54mm.step, 20_pin_male_header_2.54mm.step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]
2024-07-26 Pico firmware almost complete.
2024-08-25 Fixed Pico firmware.
2024-08-25 Added "_deps" to Pico build action ignore list, removed unused "systest" files.
2024-08-28 Minor changes to Pico firmware.
2024-10-08 Started work on Physical User Interface package for handling remote LEDs, buttons, and switches.
2024-10-23 Remove GPU device from prodcontainer.
2024-10-25 Added UI timer state updater.
2024-10-29 Fixed GUI timer state updater bug.
2024-11-03 Changed camera overlay from uncompressed stream to compressed.
    This has resulted in a significant reduction in bandwidth usage.
2024-11-07 Raspberry Pi IO handler work started.
2024-11-08 Repo re-structure.
    [12mm_key_operated_switch.step, 16mm_e-stop_button.SLDPRT, 20_pin_female_header_2.54mm.step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]
2024-11-08 Fixed pico build workflow.
2024-11-08 Fixed ROS Remote WS devcontainer mounts.
2024-11-09 Raspberry Pi IO handler completed. (untested)
2024-11-10 IO handler fix #2
    [remote_state.py]
2024-11-10 Started work on rotary encoder code.
2024-11-10 Encoder code cont'd
2024-11-10 Encoder code cont'd #2
2024-11-10 Encoder code cont'd #3
2024-11-11 Encoder tab select fix.
    [remote_state.py]
2024-11-11 Added highlight timer.
2024-11-11 Encoder handling architecture update.
2024-11-12 Test camera publisher performance improvement, encoder now supports checkboxes.
2024-11-12 Encoder now supports QSliders, QComboBox WIP.
2024-11-12 QComboBox encoder prelim. test.
2024-11-12 QComboBox encoder implementation finalised.
2024-11-12 QComboBox encoder implementation bugfix.
    [encoder_handler.py]
2024-11-13 Minor Pico firmware updates/fixes.
2024-11-13 Moved PUI buttons to QT signals.
2024-11-13 Test LED implementation.
2024-11-13 LED impl. updates.
2024-11-14 Minor Pico firmware fix.
    [remote_state.py]
2024-11-14 Make set LED state service calls async.
2024-11-14 Button functions assigned.
2024-11-14 Reduce Pico button bounce time.
2024-11-14 Initial LED switch impl.
2024-11-14 Fix minor bug with RPi-attached switches.
2024-11-14 LED switch change.
2024-11-14 Remote lock fix for LED switch.
    [config.py, remote_state.py]
2024-11-14 Added motor conrtoller switch.
2024-11-14 Revert previous faulty fix. Added some notes.
    [remote_state.py, ros_main.py]
2024-11-15 First LED tests.
2024-11-15 LED fix.
2024-11-15 Reduce power LED brightness.
2024-11-15 Turn LEDs off before quit.
2024-11-15 QT Slot fix.
2024-11-15 Power LED set change.
2024-11-16 Minor changes to Pico firmware, debouncing is now handled by the firmware.
2024-11-17 Removed e_stop topic subscription from Pico firmware, added some new options to test_camera_publisher, updated Common_libs.
2024-11-18 Joystick axis swap fix.
    [remote_state.py]
2024-11-19 Motor conrtoller LED impl.
2024-11-19 Added battery voltage warning LED.
2024-12-09 Updated SW assembly part paths.
2024-12-15 GUI yaw value display fixed, maximum linear and angular acceleration values adjusted.
    [config.py, ros_main.py]
2024-12-17 Minor fixes & additions.
    [config.py, remote_state.py, ros_main.py]
2025-01-18 Updated Pico firmware and GUI to ROS 2 Jazzy Jalisco.
2025-07-11 Major firmware rework with new Common_libs. Does not build yet.
    [hw_defs.h, joystick.cpp, leds.cpp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]
2025-07-13 Updated Common_libs, veneer function fix, now using NVIC_SystemReset().
    [main.cpp]
2025-07-15 Many updates and fixes.
    [main.cpp, sw_defs.h]
2025-07-15 More updates and fixes, serial baudrate increase.
    [leds.cpp, main.cpp, sw_defs.h]
2025-07-15 Fixes, updates, reduced baudrate a bit.
    [leds.cpp, main.cpp]
2025-07-31 Migrating from micro-ROS to TinyUSB (HID) for Pico comms. In progress...
2025-08-04 New USB HID-based Pico firmware now functional. Some features are WIP.
2025-08-05 New button implementation with better debouncing.
2025-08-06 Pico firmware now exposes 2 HID interfaces, one for the LEDs and one for the buttons and axes.
2025-08-07 Final cleanup, Pico firmware completed and tested.
2025-09-05 Added ROS driver for remote LEDs, minor modifications to Pico firmware.
2025-09-07 GUI program updates to facilitate the new HID interface used by Pico firmware.
2025-09-07 Added new joy_filter node for joystick cmd_vel filtering.
2025-09-07 Minor GUI fixes, removed e-stop assignment from left_red_btn.
    [remote_state.py, ros_main.py]
2025-09-07 Diagnostics and frame_id fixes.
    [config.py, ros_main.py]
2026-08-17 Added new fan mount, updated README.
    [16mm_e-stop_button.SLDPRT, 40x60mm_protoboard.SLDPRT, 7mm_Momentary_Button.SLDPRT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]

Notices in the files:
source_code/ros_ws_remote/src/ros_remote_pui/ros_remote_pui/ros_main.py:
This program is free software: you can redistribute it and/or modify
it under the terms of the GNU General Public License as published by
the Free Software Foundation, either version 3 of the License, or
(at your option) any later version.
